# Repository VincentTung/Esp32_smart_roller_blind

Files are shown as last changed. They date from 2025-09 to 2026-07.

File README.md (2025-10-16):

# ESP32 智能卷帘控制系统

基于ESP32和A4988步进电机驱动器的智能卷帘控制系统，支持红外遥控、蓝牙APP控制。

## 📱 系统展示

### 安装效果
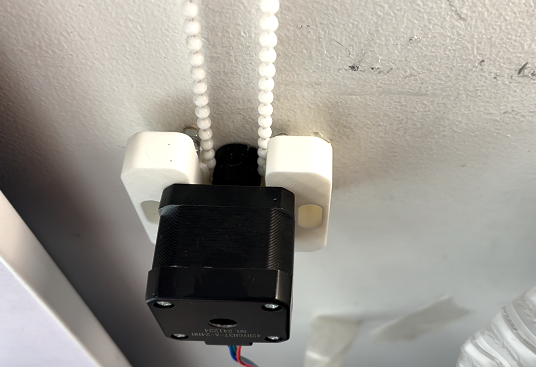
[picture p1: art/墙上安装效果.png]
墙上安装效果


### APP操作演示
APP操作演示

## 🚀 快速开始

### 硬件组件

| 组件 | 图片 | 说明 |
|---|---|---|
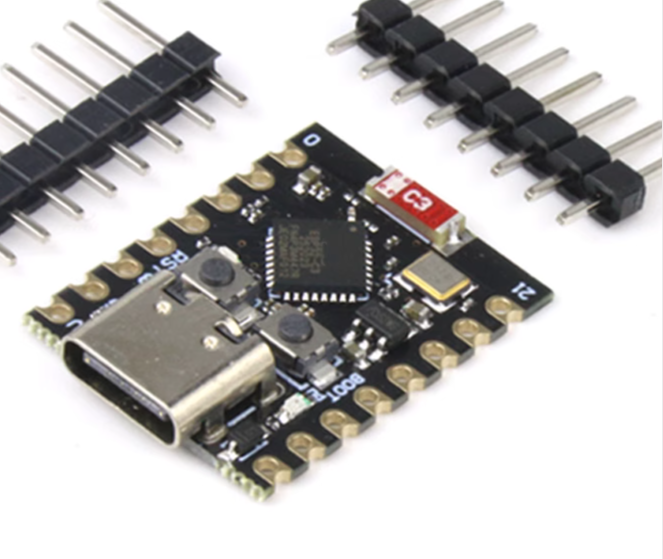
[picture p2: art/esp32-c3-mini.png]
ESP32-C3-Mini
| ESP32-C3-Mini |  | 主控制器，支持WiFi和蓝牙 |
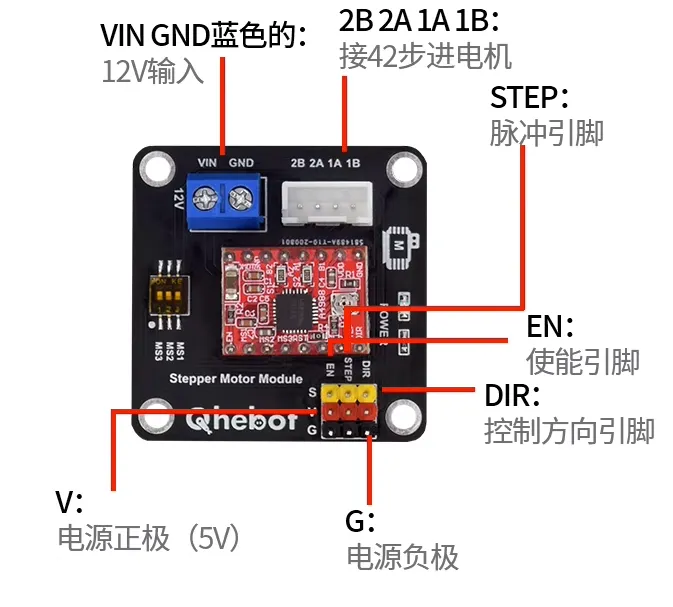
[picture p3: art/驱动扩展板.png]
驱动扩展板
| A4988驱动扩展板 |  | 步进电机驱动器 |
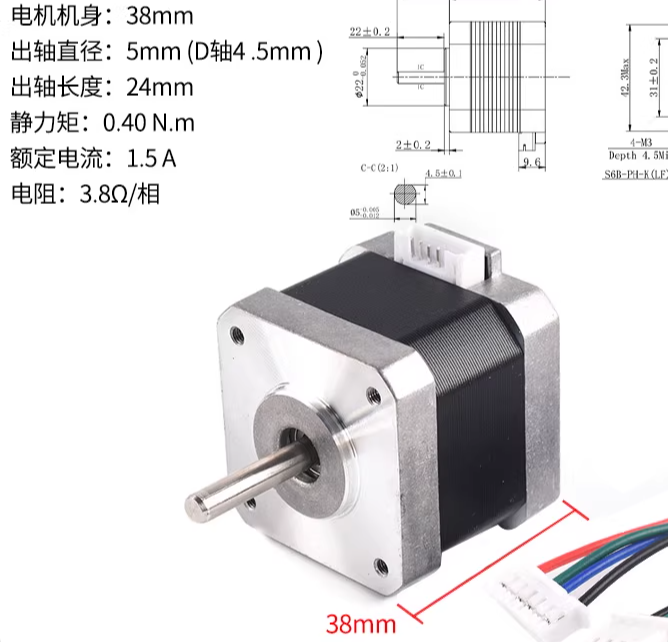
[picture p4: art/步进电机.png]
步进电机
| 42步进电机 |  | 动力源，200步/圈 |
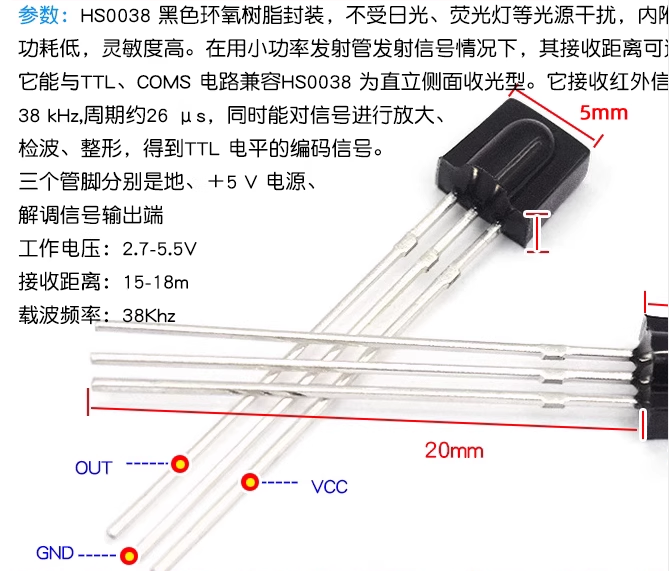
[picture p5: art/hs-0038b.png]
红外接收
| HS-0038B红外接收 |  | 红外遥控接收模块 |
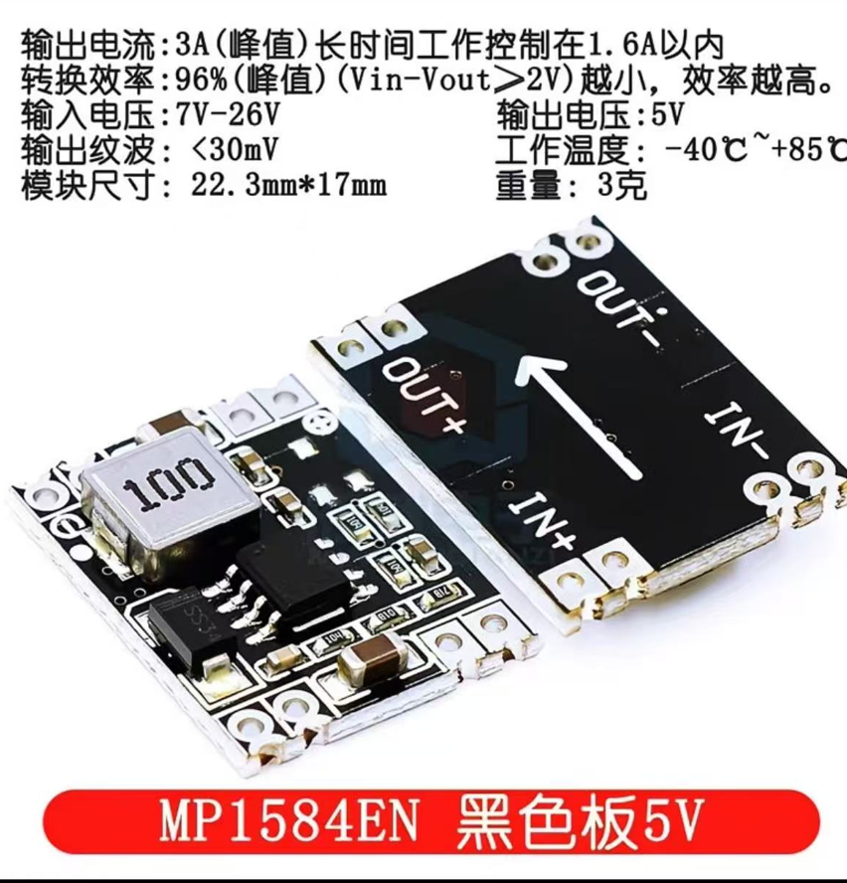
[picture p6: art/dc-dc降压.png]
DC-DC降压
| DC-DC降压模块 |  | 12V转5V电源转换 |
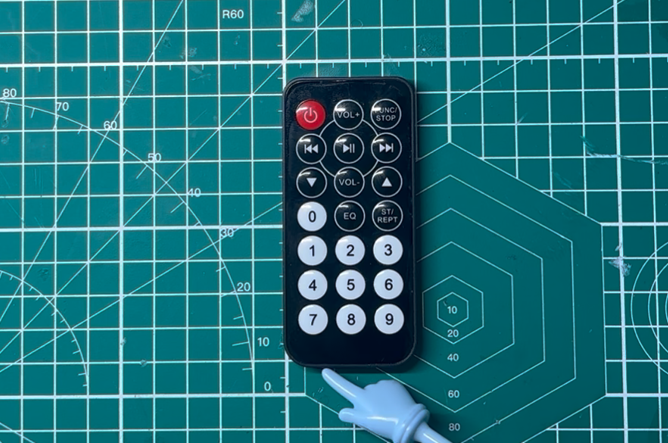
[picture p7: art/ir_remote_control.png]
红外遥控器
| 红外遥控器 |  | 遥控操作设备 |

### 硬件连接
```
ESP32 GPIO 6  -> A4988 STEP
ESP32 GPIO 7  -> A4988 DIR  
ESP32 GPIO 8  -> A4988 ENABLE
ESP32 GPIO 9  -> 红外接收模块 OUT
ESP32 3.3V    -> A4988 VDD, 红外接收模块 VCC
ESP32 GND     -> A4988 GND, 红外接收模块 GND
12V电源       -> A4988 VMOT
12V电源GND    -> A4988 GND
```

## 📱 Android APP

### 功能特性
- **蓝牙连接**: 通过BLE与ESP32设备连接
- **实时控制**: 支持窗帘的开启、关闭、停止操作
- **状态显示**: 实时显示设备连接状态和窗帘位置
- **微调功能**: 支持小幅度的窗帘位置调整
- **设置模式**: 可进入设置模式校准窗帘运行时间

### APP安装
1. 下载 `archives/app-release.apk`
2. 在Android设备上安装APK文件
3. 打开APP并授予蓝牙权限
4. 搜索并连接ESP32设备

### APP界面说明
- **连接状态**: 显示设备连接状态
- **控制按钮**: 开启、关闭、停止、微调等操作
- **设置按钮**: 进入时间设置模式
- **刷新按钮**: 重新搜索设备

## 🎮 控制方式

### 红外遥控器功能

| 按键 | 功能 | 说明 |
|---|---|---|
| 上键 | 升起窗帘 | 转动设定时间 |
| 下键 | 放下窗帘 | 转动设定时间 |
| 左键 | 微调升起 | 短时间调整 |
| 右键 | 微调放下 | 短时间调整 |
| 设置键 | 时间设置 | 进入/退出设置模式 |
| 中间键 | 停止电机 | 紧急停止 |
| 0键 | 切换方向 | 改变电机转动方向 |

### 蓝牙APP控制
- **升起/下降**: 通过APP按钮控制窗帘完全开启或关闭
- **停止**: 随时停止窗帘运动
- **微调升起/微调下降**: 小幅度的位置调整
- **设置**: 进入时间校准模式

## ⚙️ 时间设置

### 设置步骤
1. 按**设置键**（遥控器）或点击**设置按钮**（APP）进入设置模式
2. 系统开始关闭窗帘并计时
3. 窗帘完全关闭后，再次按**设置键**或点击**设置按钮**
4. 时间自动保存到EEPROM

### 调试信息
运行项目后，观察串口调试信息：
```
[14:37:16.671] [IR] 协议:8 地址:0x80 命令:0x1E
[14:37:16.705] [INFO] 接收到有效红外命令: 0x1E
[14:37:16.705] [WARN] 未知命令: 0x1E - 请使用正确的按键或检查遥控器
```

## 🔧 技术参数

- **电机**: 42步进电机，200步/圈，1/16微步进
- **速度**: 600步/秒（可调200-1000）
- **默认时间**: 5000毫秒
- **微调时间**: 1000毫秒
- **红外地址**: 0xBF00
- **蓝牙**: BLE 4.0
- **电源**: 12V直流供电

## 📁 项目结构

```
Esp32_smart_roller_blind/
├── code/
│   ├── arduino_esp32/                    # ESP32固件代码
│   │   └── skech_smart_roller_blind/
│   │       ├── skech_smart_roller_blind.ino  # 主程序
│   │       ├── BLEHandler.cpp/.h         # 蓝牙处理
│   │       └── config.h                  # 配置文件
│   └── android/                          # Android APP源码
│       └── RollerBlindControllerApp/
├── 3dmodel/                              # 3D打印文件
│   ├── gear.stl                          # 齿轮
│   └── mount.stl                         # 支架
├── art/                                  # 硬件图片和APP截图
├── archives/                             # 发布文件
│   ├── app-release.apk                   # Android APP安装包
│   └── smart_roller_blind_*.bin          # ESP32固件
└── README.md
```

## 🛠️ 开发环境

### Arduino固件开发
1. 安装Arduino IDE
2. 安装ESP32开发板支持包
3. 安装IRremote库
4. 上传代码到ESP32

### Android APP开发
1. 安装Android Studio
2. 导入项目到Android Studio
3. 配置Gradle依赖
4. 编译生成APK

## 🖨️ 3D打印

**注意**: 3D模型来自 [Printables](https://printables.com/model/1328338-high-torque-motorised-roller-blinds-mount)

感谢作者Tmate，请尊重模型的版权。

项目包含完整的3D打印文件：
- `gear.stl` - 齿轮
- `mount.stl` - 支架

## 🔍 故障排除

| 问题 | 解决方案 |
|---|---|
| 电机不转 | 检查12V电源和A4988连接 |
| 红外无响应 | 检查HS-0038B模块连接和遥控器电池 |
| 蓝牙连接失败 | 检查ESP32蓝牙功能，重启设备 |
| APP无法连接 | 确认设备在蓝牙范围内，重新搜索 |
| 转动不准确 | 重新进入设置模式校准时间 |
| 设置不保存 | 连续3次按中间键清除存储 |

## ⚠️ 安全注意事项

- 调试过程中严格操作，注意安全
- 使用12V电源，确保电源适配器质量
- 确保所有连接牢固，避免松动
- 避免短路和过载
- 安装时注意窗帘重量，确保支架牢固

## 📄 许可证

本项目仅供学习和个人使用，请遵守相关法律法规。

## 🤝 贡献

欢迎提交Issue和Pull Request来改进项目。

---

**项目特色**: 支持红外遥控和蓝牙APP双重控制，操作简单，安装方便。

---

⭐ 如果这个项目对您有帮助，请给我一个Star！

⭐ 如果您觉得我帮你节省了大量的开发时间，请扫描下方的二维码随意打赏，要是能打赏个 10.24 🐵就太👍了。您的支持将鼓励我继续进行分享。
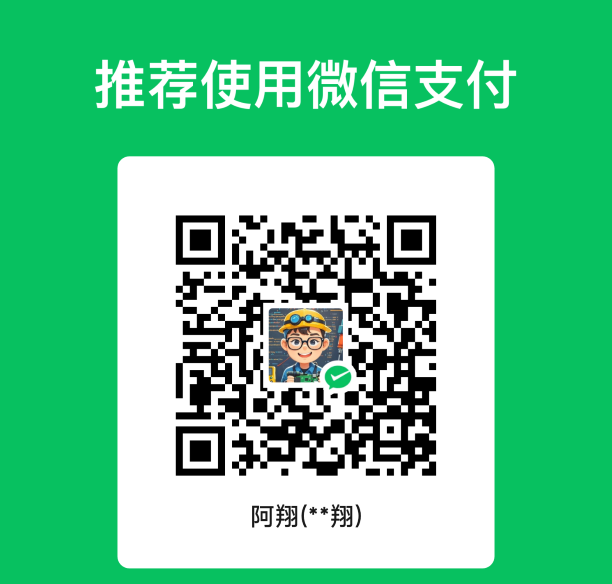
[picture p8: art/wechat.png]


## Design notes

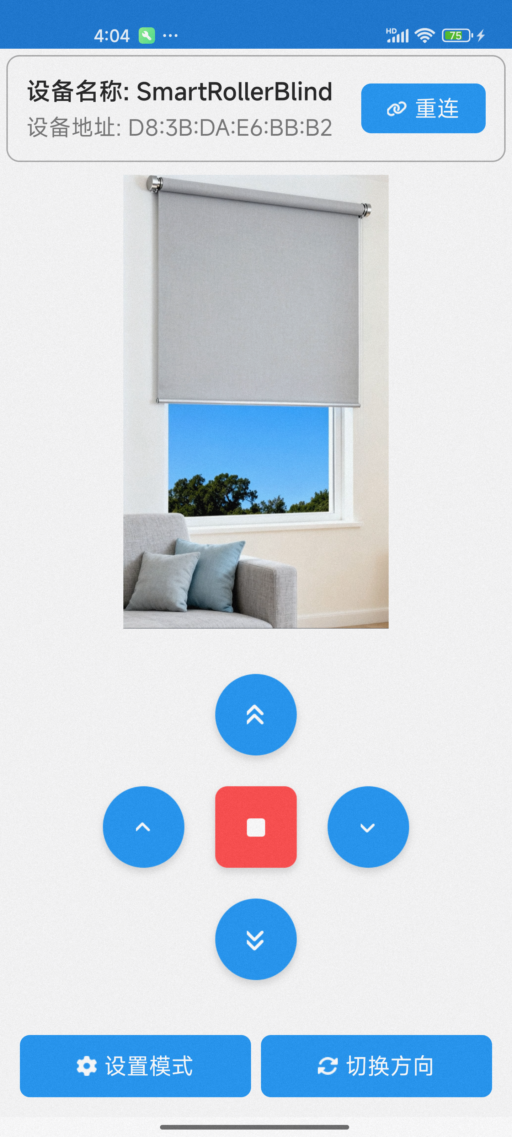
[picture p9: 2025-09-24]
art/app_screen_capture.png

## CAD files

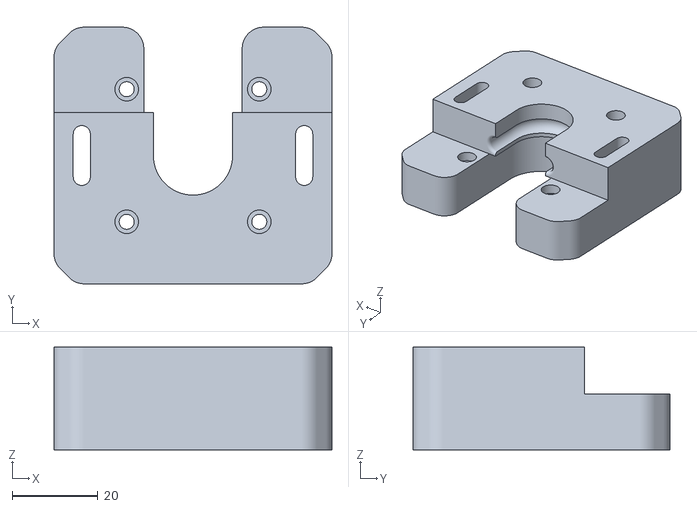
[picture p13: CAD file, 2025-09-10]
3dmodel/mount.stl
65.0 x 60.0 x 24.0

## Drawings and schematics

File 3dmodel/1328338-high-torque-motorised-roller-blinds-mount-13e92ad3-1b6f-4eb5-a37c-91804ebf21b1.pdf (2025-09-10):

## High-torque motorised roller

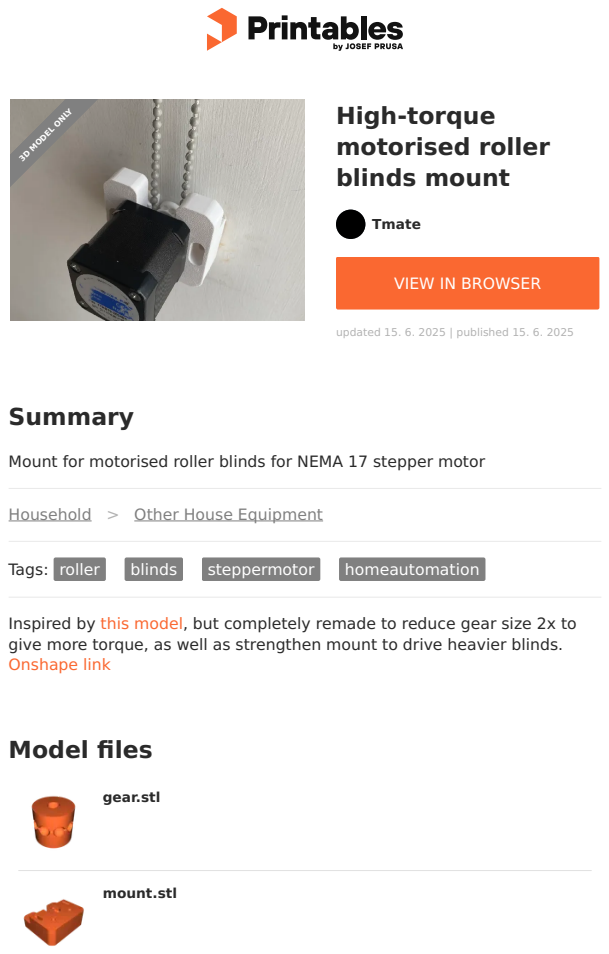
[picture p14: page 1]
Model files; Summary; Tags: roller; blinds; steppermotor; homeautomation; Tmate; blinds mount; updated 15. 6. 2025 | published 15. 6. 2025; gear.stl; mount.stl; 3D MODEL ONLY

VIEW IN BROWSER (https://printables.com/model/1328338-high-torque-motorised-roller-blinds-mount)

Mount for motorised roller blinds for NEMA 17 stepper motor

Household (https://printables.com/model?categoryId=3) > Other House Equipment (https://printables.com/model?categoryId=45)

Inspired by this model, (https://www.printables.com/model/465889-minimalistic-motorized-roller-blinds-nema-17-stepp) but completely remade to reduce gear size 2x to
give more torque, as well as strengthen mount to drive heavier blinds.
Onshape link (https://cad.onshape.com/documents/c4e8abff95d68b801ce2675b/w/7b95d8b326376692f4b0efbf/e/11ea789fce436373b3d73381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)

## License

This work is licensed under a
Creative Commons (4.0 International License)

Attribution-NonCommercial (http://creativecommons.org/licenses/by-nc/4.0/)

✖ | Sharing without ATTRIBUTION
✔ | Remix Culture allowed
✖ | Commercial Use
✖ | Free Cultural Works
✖ | Meets Open Definition

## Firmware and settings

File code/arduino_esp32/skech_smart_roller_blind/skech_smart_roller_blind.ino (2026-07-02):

/*
 * ESP32 + A4988 步进电机 + 红外接收控制程序
 * 适用于42步进电机 - 窗帘控制系统
 * 
 * 红外遥控器按键功能 (基于实际命令码):
 * 上键 (0x1) - 升起窗帘 (默认:逆时针转动指定时间)
 * 下键 (0x9) - 放下窗帘 (默认:顺时针时针转动指定时间)
 * 左键 (0x4) - 默认:升起窗帘(微调)
 * 右键 (0x6) - 默认:放下转动(微调)
 * 设置键 (0xE) - 进入设置模式开始计时关闭 / 停止计时保存时间
 * 中间键 (0x5) - 停止电机 / 连续3次清除存储
 *  9键  (0x1A) - 切换电机转动方向
 */

#include <IRremote.h>// 必须在 IRremote.h 之后，IRremote 会 #undef DEBUG_PRINT/DEBUG_PRINTLN
#include "config.h"
#include <EEPROM.h>
#include "BLEHandler.h"


// 电机参数（从config.h获取）
int speed = DEFAULT_MOTOR_SPEED;  // 步/秒 (流畅转动)

// 窗帘控制时间设置
int currentCurtainTime = DEFAULT_CURTAIN_TIME;  // 窗帘开关时间 (毫秒) - 可修改

//方向设置（可动态切换）
bool isNormalDirection = true;  // 默认方向

// 电机状态
bool motorRunning = false;
volatile bool stopRequested = false;  // 停止请求标志

// 窗帘状态标志位
bool isFullyRolledUp = false;    // 是否完全升起
bool isFullyRolledDown = false;  // 是否完全放下

// 设置模式状态
bool setMode = false;           // 是否处于设置模式
bool timingInProgress = false;  // 是否正在计时
unsigned long timingStart = 0;  // 计时开始时间
int shutdownCount = 0;          // 连续关机按键计数
unsigned long lastShutdownTime = 0; // 上次关机按键时间


// 红外接收状态
uint32_t lastIRCommand = 0;
unsigned long lastIRTime = 0;
const unsigned long IR_DEBOUNCE_TIME = 200; // 200ms防抖时间

// BLE处理器
#if ENABLE_BLE
BLEHandler* bleHandler = nullptr;
#endif


// BLE命令队列（用于非阻塞处理）
volatile bool bleStopRequested = false;
volatile bool bleUpRequested = false;
volatile bool bleDownRequested = false;
volatile bool bleLeftRequested = false;
volatile bool bleRightRequested = false;
volatile bool bleSetRequested = false;
volatile bool bleDirectionRequested = false;
 
 // 辅助函数：重置窗帘状态
void resetCurtainState() {
  isFullyRolledUp = false;
  isFullyRolledDown = false;
  stopRequested = false;
}

// 辅助函数：获取方向参数
bool getDirection(bool isUp) {
  if (isUp) {
    return isNormalDirection; // 升起方向
  } else {
    return !isNormalDirection; // 放下方向
  }
}

// 辅助函数：验证红外命令有效性
bool isValidIRCommand(uint32_t command, uint8_t protocol) {
  return command != 0xFFFFFFFF && protocol != 0;
}

// 辅助函数：判断是否应该处理命令（防抖机制）
bool shouldProcessCommand(uint32_t command, unsigned long currentTime, unsigned long debounceTime) {
  return command != lastIRCommand || (currentTime - lastIRTime) > debounceTime;
}

// 辅助函数：更新红外状态
void updateIRState(uint32_t command, unsigned long currentTime) {
  lastIRCommand = command;
  lastIRTime = currentTime;
}

// 辅助函数：打印红外信号详细信息
void printIRSignal(uint32_t address, uint32_t command, uint8_t protocol, const char* context = "") {
  DEBUG_PRINT("红外信号");
  if (strlen(context) > 0) {
    DEBUG_PRINT(" [");
    DEBUG_PRINT(context);
    DEBUG_PRINT("]");
  }
  DEBUG_PRINT(" - 协议:");
  DEBUG_PRINT(protocol);
  DEBUG_PRINT(" 地址:0x");
  DEBUG_PRINTF("%X", address);
  DEBUG_PRINT(" 命令:0x");
  DEBUG_PRINTF("%X", command);
  DEBUG_PRINT(" 位数:");
  DEBUG_PRINT(IrReceiver.decodedIRData.numberOfBits);
  DEBUG_PRINT(" 标志:");
  DEBUG_PRINTF("%X", IrReceiver.decodedIRData.flags);
  DEBUG_PRINTLN();
}

// 电源管理函数（简化版 - 已移除睡眠逻辑）

bool executeStepControl(unsigned long stepDelay, unsigned long &lastStepTime, bool &stepState, int &totalSteps, unsigned long startTime, bool isSetMode = false) {
  unsigned long currentTime = millis();
  if (currentTime - lastStepTime >= stepDelay / 1000) {  // 转换为毫秒
    // 执行步进脉冲 - 与rotateForTime完全相同的逻辑
    if (!stepState) {
      digitalWrite(STEP_PIN, HIGH);
      stepState = true;
    } else {
      digitalWrite(STEP_PIN, LOW);
      stepState = false;
      lastStepTime = currentTime; // 在LOW状态时更新时间，确保时序准确
      totalSteps++;
      
      // 每2000步打印一次进度
      if (totalSteps % 2000 == 0) {
        unsigned long elapsed = currentTime - startTime;
        if (isSetMode) {
          Serial.print("设置模式 - 已执行 ");
        } else {
          Serial.print("已执行 ");
        }
        Serial.print(totalSteps);
        Serial.print(" 步，用时 ");
        Serial.print(elapsed);
        Serial.println(" 毫秒");
      }
    }
    return true; // 执行了步进
  }
  return false; // 未执行步进
}

// 设置模式旋转处理函数 - 使用与rotateForTime完全相同的方法
void handleSetModeRotation() {
  // 确保电机已启用
  digitalWrite(ENABLE_PIN, LOW);
  
  // 使用与rotateForTime完全相同的步进控制逻辑
  static unsigned long stepDelay = 1000000 / speed;
  static unsigned long lastStepTime = 0;
  static bool stepState = false;
  static int totalSteps = 0;
  static unsigned long lastSetModeTime = 0;
  static unsigned long startTime = 0;
  static bool directionSet = false;
  static bool setModeRunning = false;
  
  // 每次进入设置模式时重新初始化所有变量
  if (timingStart != lastSetModeTime) {
    stepState = false;
    lastStepTime = 0;
    totalSteps = 0;
    lastSetModeTime = timingStart;
    startTime = millis();
    directionSet = false;
    setModeRunning = true;
    stepDelay = 1000000 / speed; // 重新计算步进延迟
  }
  
  // 设置方向（只设置一次）
  if (!directionSet) {
    digitalWrite(DIR_PIN, getDirection(false) ? HIGH : LOW); // 放下方向
    directionSet = true;
  }
  
  // 检查停止标志
  #if ENABLE_BLE
    if (bleStopRequested || stopRequested) {
      exitSetMode();
      return;
    }
  #else
    if (stopRequested) {
      exitSetMode();
      return;
    }
  #endif
  
  // 使用与rotateForTime完全相同的执行方式：在循环中连续执行步进控制
  if (setModeRunning) {
    // 使用与rotateForTime完全相同的步进控制函数
    if (executeStepControl(stepDelay, lastStepTime, stepState, totalSteps, startTime, true)) {
      // 每10步检查一次停止标志（与rotateForTime保持一致）
      if (totalSteps % 10 == 0) {
        #if ENABLE_BLE
          if (bleStopRequested || stopRequested) {
            exitSetMode();
            return;
          }
        #else
          if (stopRequested) {
            exitSetMode();
            return;
          }
        #endif
      }
    }
    
    // 与rotateForTime保持完全一致：让出CPU时间给其他任务
    delay(1);  
    
  }
}

// 退出设置模式
void exitSetMode() {
  unsigned long duration = millis() - timingStart;
  Serial.print("设置模式结束，窗帘关闭时间: ");
  Serial.print(duration);
  Serial.println(" 毫秒");
  
  // 停止电机
  digitalWrite(ENABLE_PIN, HIGH);
  motorRunning = false;
  timingInProgress = false;
  setMode = false;
  
  Serial.print("exitSetMode() 设置 setMode = ");
  Serial.println(setMode ? "true" : "false");
  
  // 保存时间
  currentCurtainTime = duration;
  saveCurtainTime();
  isFullyRolledDown = true;
  isFullyRolledUp = false;
  
  // 清除停止标志
  stopRequested = false;
  #if ENABLE_BLE
    bleStopRequested = false;
  #endif
  
  Serial.println("=== 退出设置模式 ===");
}

// 打印设置模式状态
void printSetModeStatus(unsigned long elapsed, int totalSteps, unsigned long stepDelay) {
  DEBUG_PRINT("设置模式 - 已计时: ");
  DEBUG_PRINT(elapsed);
  DEBUG_PRINT(" 毫秒 (转速: ");
  DEBUG_PRINT(speed);
  DEBUG_PRINT(" 步/秒, 总步数: ");
  DEBUG_PRINT(totalSteps);
  DEBUG_PRINT(", 步进延迟: ");
  DEBUG_PRINT(stepDelay);
  DEBUG_PRINT(" 微秒, 实际转速: ");
  if (elapsed > 0) {
    DEBUG_PRINT((totalSteps * 1000) / elapsed);
    DEBUG_PRINT(" 步/秒");
  } else {
    DEBUG_PRINT("计算中");
  }
  DEBUG_PRINTLN(")");
}

void setup() {
   Serial.begin(9600);
   DEBUG_PRINTLN("ESP32-C3 + A4988 步进电机 + 红外控制");
   
   // 设置引脚
   pinMode(STEP_PIN, OUTPUT);
   pinMode(DIR_PIN, OUTPUT);
   pinMode(ENABLE_PIN, OUTPUT);
   
   // 初始状态
   digitalWrite(STEP_PIN, LOW);
   digitalWrite(DIR_PIN, LOW);
   digitalWrite(ENABLE_PIN, HIGH);  // 禁用电机（待机状态）
  // 读取存储的窗帘时间
  loadCurtainTime();
  
  // 读取存储的方向设置
  loadDirectionSetting();
  // 初始化红外接收 (0038k模块)
  DEBUG_PRINT("初始化红外接收模块，引脚: ");
  DEBUG_PRINTLN(IR_RECEIVE_PIN);
  IrReceiver.begin(IR_RECEIVE_PIN, false);
  DEBUG_PRINTLN("红外接收模块初始化完成");
  
  // 初始化BLE（根据配置决定）
  #if ENABLE_BLE
    bleHandler = new BLEHandler();
    bleHandler->init();
    bleHandler->setCommandCallbacks(
      handleBLEUpCommand,      // 升起窗帘
      handleBLEDownCommand,    // 放下窗帘
      handleBLELeftCommand,    // 微调升起
      handleBLERightCommand,   // 微调放下
      handleBLEStopCommand,    // 停止电机
      handleBLESetCommand,     // 设置模式
      handleBLEDirectionCommand // 切换方向
    );
    bleHandler->startAdvertising();
    Serial.println("BLE已初始化并开始广播");
  #else
    Serial.println("BLE已禁用（节省电量）");
  #endif
  
  // 初始化窗帘状态标志位
  isFullyRolledUp = false;
  isFullyRolledDown = false;
  
  // 初始化完成
  
  DEBUG_PRINTLN("电机已启用，0038k红外接收模块已初始化");
  #if ENABLE_BLE
    Serial.println("等待红外命令或BLE命令...");
  #else
    Serial.println("等待红外命令...");
  #endif
  printIRCommands();
   

 }
 
void loop() {
  // 在设置模式下减少BLE状态检查频率，避免影响电机转动
  #if ENABLE_BLE
    static unsigned long lastBLEStatusTime = 0;
    if (!setMode && millis() - lastBLEStatusTime > 10000) { // 非设置模式下每10秒检查一次
      DEBUG_PRINTLN(bleHandler != nullptr ? "BLE处理器状态正常" : "BLE处理器为空！");
      lastBLEStatusTime = millis();
    }
  #endif
  
  // 处理BLE命令队列（优先级最高）
  #if ENABLE_BLE
    if (bleStopRequested) {
      bleStopRequested = false;
      stopRequested = true;
      stopMotor();
    }
    
    if (bleUpRequested) {
      bleUpRequested = false;
      if (!isFullyRolledUp) {
        resetCurtainState();
        rollUpCurtain();
      }
    }
    
    if (bleDownRequested) {
      bleDownRequested = false;
      if (!isFullyRolledDown) {
        resetCurtainState();
        layDownCurtain();
      }
    }
    
    if (bleLeftRequested) {
      bleLeftRequested = false;
      resetCurtainState();
      rotateForTime(SIDE_KEY_TIME, getDirection(true)); // 微调升起
    }
    
    if (bleRightRequested) {
      bleRightRequested = false;
      resetCurtainState();
      rotateForTime(SIDE_KEY_TIME, getDirection(false)); // 微调放下
    }
    
    if (bleSetRequested) {
      bleSetRequested = false;
      handleSetKey();
    }
    
    if (bleDirectionRequested) {
      bleDirectionRequested = false;
      handleDirectionKey();
    }
  #endif
  
  // 检查红外信号
  if (IrReceiver.decode()) {
    DEBUG_PRINTLN("检测到红外信号！");
    uint32_t address = IrReceiver.decodedIRData.address;
    uint32_t command = IrReceiver.decodedIRData.command;
    uint8_t protocol = IrReceiver.decodedIRData.protocol;
    
    // 打印所有接收到的红外信号（包括无效信号）
    printIRSignal(address, command, protocol, "接收");
    
    // 过滤无效信号：协议:0、地址:0x0、命令:0x0 不处理
    if (protocol == 0 && address == 0x0 && command == 0x0) {
      DEBUG_PRINTLN("无效信号，忽略");
      IrReceiver.resume();
      return; 
    }
    
  // 在设置模式下，最小化红外信号处理，优先保证步进控制
  if (setMode) {
    // 设置模式下只处理有效地址的信号，快速跳过无效信号
    if (address != IR_ADDRESS) {
      IrReceiver.resume();
      return;
    }
    
    // 设置模式下快速处理命令，减少阻塞时间
    unsigned long currentTime = millis();
    if (isValidIRCommand(command, protocol)) {
      if (shouldProcessCommand(command, currentTime, 200)) { // 设置模式防抖时间：200ms
        DEBUG_PRINT("设置模式接收到有效命令: 0x");
        DEBUG_PRINTF("%X\n", command);
        handleIRCommand(command);
        updateIRState(command, currentTime);
      } else {
        DEBUG_PRINTLN("设置模式：重复命令，忽略");
      }
    } else {
      DEBUG_PRINTLN("设置模式：无效命令，忽略");
    }
    IrReceiver.resume();
    return;
  } else {
      // 非设置模式下的正常处理
      // 验证地址
      if (address != IR_ADDRESS) {
        DEBUG_PRINT("地址不匹配，期望:0x");
        DEBUG_PRINTF("%X", IR_ADDRESS);
        DEBUG_PRINT(" 实际:0x");
        DEBUG_PRINTF("%X\n", address);
        IrReceiver.resume();
        return;
      }
      
      DEBUG_PRINTLN("地址匹配，处理命令");
    }

    unsigned long currentTime = millis();
    
    // 非设置模式下的正常处理
    if (isValidIRCommand(command, protocol)) {
      // 电机运行时立即处理停止命令，否则使用防抖机制
      if (motorRunning && command == IR_KEY_SHUTDOWN) {
        DEBUG_PRINTLN("电机运行时接收到有效停止命令，立即处理");
        handleIRCommand(command);
        updateIRState(command, currentTime);
      } else if (shouldProcessCommand(command, currentTime, IR_DEBOUNCE_TIME)) {
        DEBUG_PRINTLN("处理有效命令");
        handleIRCommand(command);
        updateIRState(command, currentTime);
      } else {
        DEBUG_PRINTLN("重复命令，已忽略");
      }
    } else {
      DEBUG_PRINTLN("无效信号，已忽略");
    }
    
    IrReceiver.resume();
  }
  
  // 检查设置模式下的持续转动
  if (setMode && timingInProgress && motorRunning) {
    handleSetModeRotation();
  }
  
  // 调试输出：在非设置模式下每30秒显示一次状态，设置模式下不输出
  static unsigned long lastDebugTime = 0;
  if (!setMode && millis() - lastDebugTime > 30000) {
    DEBUG_PRINT("系统运行中 - setMode: ");
    DEBUG_PRINT(setMode ? "true" : "false");
    DEBUG_PRINT(", timingInProgress: ");
    DEBUG_PRINT(timingInProgress ? "true" : "false");
    DEBUG_PRINT(", motorRunning: ");
    DEBUG_PRINT(motorRunning ? "true" : "false");
    DEBUG_PRINT(", 等待红外信号...");
    DEBUG_PRINTLN();
    lastDebugTime = millis();
  }
  
  // 正常运行
 
  if (!setMode) {
    delay(IDLE_DELAY_MS); // 使用配置的延迟时间，避免过度占用CPU
  }
  // 设置模式下不添加任何延迟，因为handleSetModeRotation内部已有delay(1)
  
  // 安全措施：如果不在设置模式且电机应该停止，确保电机被禁用
  if (!setMode && !motorRunning) {
    digitalWrite(ENABLE_PIN, HIGH);  // 确保电机被禁用
  }
}

// 转动指定时长 (毫秒) - 非阻塞版本
void rotateForTime(int duration, bool clockwise) {
  Serial.print("rotateForTime函数接收参数: duration=");
  Serial.print(duration);
  Serial.print(", clockwise=");
  Serial.println(clockwise ? "true" : "false");
  
  digitalWrite(ENABLE_PIN, LOW);  // 启用电机
  digitalWrite(DIR_PIN, clockwise ? HIGH : LOW);
  
  unsigned long startTime = millis();
  unsigned long stepDelay = 1000000 / speed;
  int stepCount = 0;
  unsigned long lastStepTime = 0;
  
  Serial.print("开始旋转，持续时间: ");
  Serial.print(duration);
  Serial.print(" 毫秒，方向: ");
  Serial.println(clockwise ? "顺时针" : "逆时针");
  Serial.print("步进延迟: ");
  Serial.print(stepDelay);
  Serial.println(" 微秒");
  
  // 完全非阻塞方式：使用状态机而不是while循环
  bool stepState = false;  // 移除static，每次调用函数时重新初始化
  while (millis() - startTime < duration) {
    // 每次循环都检查停止标志（提高响应速度）
    #if ENABLE_BLE
      if (bleStopRequested) {
        Serial.println("旋转过程中接收到BLE停止命令，立即停止");
        bleStopRequested = false;  // 清除标志
        break;
      }
    #endif
    
    if (stopRequested) {
      Serial.println("旋转过程中接收到停止命令，立即停止");
      break;
    }
    
    // 使用统一的步进控制函数，确保与设置模式完全一致
    if (executeStepControl(stepDelay, lastStepTime, stepState, stepCount, startTime, false)) {
      // 每10步检查一次红外信号（减少检查频率提高流畅性）
      if (stepCount % 10 == 0) {
        // 检查红外信号
        if (IrReceiver.decode()) {
          uint32_t command = IrReceiver.decodedIRData.command;
          uint32_t address = IrReceiver.decodedIRData.address;
          uint8_t protocol = IrReceiver.decodedIRData.protocol;
          
          // 只有在接收到有效的停止信号时才停止（地址不为0x0，协议不为0）
          if (command == IR_KEY_SHUTDOWN && address != 0x0 && protocol != 0) {
            DEBUG_PRINTLN("旋转过程中接收到有效红外停止信号，立即停止");
            stopRequested = true;
            IrReceiver.resume();
            break;
          }
          IrReceiver.resume();
        }
      }
    }
    
    delay(1);  // 1毫秒延迟，让BLE回调有机会执行
  }
  
  unsigned long actualDuration = millis() - startTime;
  Serial.print("旋转完成，总步数: ");
  Serial.print(stepCount);
  Serial.print("，实际持续时间: ");
  Serial.print(actualDuration);
  Serial.print(" 毫秒，停止原因: ");
  Serial.println(stopRequested ? "被中断" : "时间到");
  
  // 确保电机被禁用
  digitalWrite(ENABLE_PIN, HIGH);
}

// 设置速度
void setSpeed(int newSpeed) {
  speed = constrain(newSpeed, MIN_MOTOR_SPEED, MAX_MOTOR_SPEED);  // 限制速度范围，流畅转动设置
  DEBUG_PRINT("速度设置为: ");
  DEBUG_PRINT(speed);
  DEBUG_PRINTLN(" 步/秒");
}
 
// 打印红外命令说明
void printIRCommands() {
  Serial.println("红外遥控器按键功能:");
  Serial.print("上键 (0x1) - 窗帘升起");
  Serial.print(currentCurtainTime);
  Serial.println("毫秒)");
  Serial.print("下键 (0x9) - 窗帘放下");
  Serial.print(currentCurtainTime);
  Serial.println("毫秒)");
  Serial.println("左键 (0x4) - 微调升起");
  Serial.println("右键 (0x6) - 微调放下");
  Serial.println("设置键 (0xE) - 进入设置模式开始计时关闭 / 停止计时保存时间");
  Serial.println("0键 (0x0) - 停止电机 / 连续3次清除存储");
  Serial.println("方向键 (0x1A) - 切换电机转动方向");
  Serial.println("-------------------");
}
 
// 处理红外命令
void handleIRCommand(uint32_t command) {
  DEBUG_PRINT("接收到有效红外命令: 0x");
  DEBUG_PRINTF("%X\n", command);
  
  switch (command) {
    case IR_KEY_UP:
      if (isFullyRolledUp) {
        DEBUG_PRINTLN("窗帘已经完全升起，停止动作");
        break;
      }
      DEBUG_PRINTLN("执行: 窗帘升起");
      DEBUG_PRINT("isNormalDirection = ");
      DEBUG_PRINTLN(isNormalDirection ? "true" : "false");
      isFullyRolledDown = false;
      isFullyRolledUp = false;
      rollUpCurtain();
      break;
      
    case IR_KEY_DOWN:
      if (isFullyRolledDown) {
        Serial.println("窗帘已经完全放下，无响应");
        break;
      }
      isFullyRolledDown = false;
      isFullyRolledUp = false;
      Serial.println("执行: 窗帘放下");
      Serial.print("isNormalDirection = ");
      Serial.println(isNormalDirection ? "true" : "false");
      layDownCurtain();
      break;
      
    case IR_KEY_LEFT: {
      Serial.println("执行: 微调升起（丝滑模式）");
      resetCurtainState();
      rotateForTime(SIDE_KEY_TIME, getDirection(true)); // 微调升起
      break;
    }
      
    case IR_KEY_RIGHT: {
      Serial.println("执行: 微调放下（丝滑模式）");
      resetCurtainState();
      rotateForTime(SIDE_KEY_TIME, getDirection(false)); // 微调放下
      break;
    }
      
    case IR_KEY_SET:
      handleSetKey();
      break;
      
    case IR_KEY_SHUTDOWN:
      handleShutdownKey();
      break;
      
    case IR_KEY_DIRECTION:
      handleDirectionKey();
      break;
      
    default:
      Serial.print("未知命令: 0x");
      Serial.print(command, HEX);
      break;
  }
}
 
// 停止电机
void stopMotor() {
  digitalWrite(ENABLE_PIN, HIGH);  // 禁用电机
  motorRunning = false;
  
  // 如果在设置模式下停止，需要退出设置模式
  if (setMode) {
    exitSetMode();
  }
  
  Serial.println("电机已停止");
  delay(100);
  // 注意：不重新启用电机，保持待机状态
}

// 打开窗帘
void rollUpCurtain() {
  Serial.println("=== 开始升起窗帘 ===");
  DEBUG_PRINT("当前速度设置: ");
  DEBUG_PRINT(speed);
  DEBUG_PRINTLN(" 步/秒");
  
  motorRunning = true;
  stopRequested = false;  // 重置停止标志
  
  rotateForTime(currentCurtainTime, getDirection(true));
  
  motorRunning = false;
  if (!stopRequested) {
    Serial.println("窗帘已升起");
    isFullyRolledUp = true;
    isFullyRolledDown = false;
  } else {
    Serial.println("窗帘升起被中断");
  }
  
  stopRequested = false;
  Serial.println("=== 升起窗帘完成 ===");
}

// 放下窗帘
void layDownCurtain() {
  motorRunning = true;
  stopRequested = false;
  rotateForTime(currentCurtainTime, getDirection(false));
  
  motorRunning = false;
  if (!stopRequested) {
    Serial.println("窗帘已放下");
    isFullyRolledDown = true;
    isFullyRolledUp = false;
  } else {
    Serial.println("窗帘放下被中断");
  }
  
  stopRequested = false;
  Serial.println("=== 放下窗帘完成 ===");
}
 

// 处理设置键
void handleSetKey() {
  Serial.print("handleSetKey() 被调用，当前 setMode = ");
  Serial.println(setMode ? "true" : "false");
  
  if (!setMode) {
    // 进入设置模式并开始计时关闭
    Serial.println("=== 进入设置模式 ===");
    DEBUG_PRINT("当前转速: ");
    DEBUG_PRINT(speed);
    DEBUG_PRINTLN(" 步/秒 (流畅转动设置，与正常使用转速一致)");
    Serial.println("开始计时关闭窗帘，观察窗帘完全关闭后按设置键停止");
    
    setMode = true;
    timingInProgress = true;
    timingStart = millis();
    
    // 清除停止标志
    stopRequested = false;
    #if ENABLE_BLE
      bleStopRequested = false;
    #endif
    
     // 开始关闭窗帘（放下方向）
     digitalWrite(ENABLE_PIN, LOW);  // 启用电机
     digitalWrite(DIR_PIN, getDirection(false) ? HIGH : LOW);  // 放下方向
     motorRunning = true;
    
    Serial.println("设置模式：电机已启动，开始持续转动");
    DEBUG_PRINT("方向: 放下方向, 转速: ");
    DEBUG_PRINT(speed);
    DEBUG_PRINTLN(" 步/秒");
    
  } else {
    // 在设置模式中，设置停止标志（使用和BLE停止相同的方式）
    Serial.println("第二次按下SET键，设置停止标志");
    stopRequested = true;
    #if ENABLE_BLE
      bleStopRequested = true;  // 同时设置BLE停止标志，确保rotateForTime能检测到
    #endif
  }
}

// 处理关机键
void handleShutdownKey() {
  unsigned long currentTime = millis();
  
  // 检查是否在设置模式
  if (setMode) {
    Serial.println("设置模式下按关机键，退出设置模式");
    exitSetMode();
    return;
  }
  
  // 检查连续按键
  if (currentTime - lastShutdownTime < 2000) { // 2秒内
    shutdownCount++;
  } else {
    shutdownCount = 1; // 重新开始计数
  }
  
  lastShutdownTime = currentTime;
  
  if (shutdownCount >= 3) {
    // 连续3次，清除存储
    Serial.println("连续3次关机键，清除存储的时间设置");
    clearCurtainTime();
    shutdownCount = 0;
  } else {
    // 正常停止电机
    Serial.println("执行: 停止电机");
    stopRequested = true;
    stopMotor();
  }
}

// 保存窗帘时间到EEPROM
void saveCurtainTime() {
  EEPROM.begin(EEPROM_SIZE);
  EEPROM.put(EEPROM_CURTAIN_TIME_ADDR, currentCurtainTime);
  EEPROM.commit();
  EEPROM.end();
  Serial.println("窗帘时间已保存到EEPROM");
}

// 从EEPROM读取窗帘时间
void loadCurtainTime() {
  EEPROM.begin(EEPROM_SIZE);
  int savedTime;
  EEPROM.get(EEPROM_CURTAIN_TIME_ADDR, savedTime);
  EEPROM.end();
  
  if (savedTime > 0 && savedTime < 60000) { // 合理范围检查
    currentCurtainTime = savedTime;
    Serial.print("从EEPROM读取窗帘时间: ");
    Serial.print(currentCurtainTime);
    Serial.println(" 毫秒");
  } else {
    currentCurtainTime = DEFAULT_CURTAIN_TIME;
    Serial.print("使用默认窗帘时间: ");
    Serial.print(currentCurtainTime);
    Serial.println(" 毫秒");
  }
}

// 清除存储的窗帘时间
void clearCurtainTime() {
  EEPROM.begin(EEPROM_SIZE);
  EEPROM.put(EEPROM_CURTAIN_TIME_ADDR, 0); // 写入0表示无效
  EEPROM.commit();
  EEPROM.end();
  
  currentCurtainTime = DEFAULT_CURTAIN_TIME;
  Serial.print("已清除存储，恢复默认时间: ");
  Serial.print(currentCurtainTime);
  Serial.println(" 毫秒");
}

// 处理方向切换键
void handleDirectionKey() {
  // 切换方向
  Serial.print("切换前 isNormalDirection = ");
  Serial.println(isNormalDirection ? "true" : "false");
  
  if (isNormalDirection == true) {
    isNormalDirection = false;
    Serial.println("设置 isNormalDirection = false");
  } else {
    isNormalDirection = true;
    Serial.println("设置 isNormalDirection = true");
  }
  
  Serial.print("切换后 isNormalDirection = ");
  Serial.println(isNormalDirection ? "true" : "false");
  
  // 保存方向设置
  saveDirectionSetting();
  isFullyRolledUp = false;    
  isFullyRolledDown = false;
  Serial.print("方向已切换为: ");
  Serial.println(isNormalDirection ? "RIGHT模式" : "LEFT模式");
  Serial.println("新的方向设置已保存到EEPROM");
}

// 保存方向设置到EEPROM
void saveDirectionSetting() {
  EEPROM.begin(EEPROM_SIZE);
  EEPROM.put(EEPROM_DIRECTION_ADDR, isNormalDirection);  // 存储方向设置
  EEPROM.commit();
  EEPROM.end();
  Serial.println("方向设置已保存到EEPROM");
}
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

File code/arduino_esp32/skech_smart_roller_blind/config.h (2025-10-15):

#ifndef CONFIG_H
#define CONFIG_H

 // 引脚定义
 // 42步进电机
/* 
 * 连接:
 * ESP32 GPIO 6 -> A4988 STEP
 * ESP32 GPIO 7 -> A4988 DIR
 * ESP32 GPIO 8 -> A4988 ENABLE (可选)
 * ESP32 GPIO 9 -> 红外接收模块 OUT
 * ESP32 3.3V    -> A4988 VDD, 红外接收模块 VCC
 * ESP32 GND     -> A4988 GND, 红外接收模块 GND
 * 12V电源       -> A4988 VMOT
 * 12V电源GND    -> A4988 GND
 *
 */
 #define STEP_PIN 6
 #define DIR_PIN 7
 #define ENABLE_PIN 8
 //红外
 #define IR_RECEIVE_PIN 9
 
//红外地址  （根据实际接收到的地址修改）
#define IR_ADDRESS  0xBF00
// 红外命令定义 (基于实际接收到的命令码)
#define IR_KEY_UP 0x1  // val+
#define IR_KEY_DOWN 0x9 // val-
#define IR_KEY_LEFT 0x4 // <
#define IR_KEY_RIGHT 0x6 // >
#define IR_KEY_SHUTDOWN 0x5  //关闭
#define IR_KEY_SET 0xE //   ST/REPT
#define IR_KEY_DIRECTION 0x1A  // 数字9

//开关窗帘时间默认时间
const int DEFAULT_CURTAIN_TIME = 5000;  // 默认窗帘开关时间 (毫秒)
// 左右按键转动时间设置 
const int SIDE_KEY_TIME = 1000;  // 左右按键转动时间 (毫秒) 上下微调响应参数调这个

const int DEFAULT_IS_NORMAL_DIRECTION = true;

// EEPROM 配置
#define EEPROM_SIZE 512                    // EEPROM 大小
#define EEPROM_CURTAIN_TIME_ADDR 0         // 窗帘时间存储地址
#define EEPROM_DIRECTION_ADDR 4            // 方向设置存储地址
#define EEPROM_DIRECTION_INIT_FLAG_ADDR 5  // 方向设置初始化标志地址

// BLE配置
#define ENABLE_BLE true  // 蓝牙开关：true=开启，false=关闭（节省电量）
#define BLE_DEVICE_NAME "SmartRollerBlind"
#define BLE_SERVICE_UUID "12345678-1234-1234-1234-123456789abc"
#define BLE_CHARACTERISTIC_CONTROL_UUID "12345678-1234-1234-1234-123456789def"

//微步分辨率配置
// MS1/2/3
// 默认步距角电机：200步/圈（1.8°）
// L/L/L: 全步进 (1/1) → 200步/圈
// H/L/L: 1/2 微步 → 400步/圈
// L/H/L: 1/4 微步 → 800步/圈
// H/H/L: 1/8 微步 → 1600步/圈
// H/H/H: 1/16 微步 → 3200步/圈

// 步进电机配置         // 全步进
#define DEFAULT_MOTOR_SPEED 1000   // 默认电机转速（步/秒）
#define MIN_MOTOR_SPEED 200       // 最小电机转速（步/秒）
#define MAX_MOTOR_SPEED 1000      // 最大电机转速（步/秒）

// 电源管理配置
#define ENABLE_DEBUG_OUTPUT true  // 调试输出开关：true=开启，false=关闭（节省电量）
#define IDLE_DELAY_MS 50          // 空闲时延迟（毫秒），降低CPU使用率

// 调试输出宏定义
#if ENABLE_DEBUG_OUTPUT
  #define DEBUG_PRINT(x) Serial.print(x)
  #define DEBUG_PRINTLN(x) Serial.println(x)
  #define DEBUG_PRINTF(x, ...) Serial.printf(x, __VA_ARGS__)
#else
  #define DEBUG_PRINT(x)
  #define DEBUG_PRINTLN(x)
  #define DEBUG_PRINTF(x, ...)
#endif


#endif // 

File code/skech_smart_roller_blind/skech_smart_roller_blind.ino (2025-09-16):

/*
 * ESP32 + A4988 步进电机 + 红外接收控制程序
 * 适用于42步进电机 - 窗帘控制系统
 * 
 * 红外遥控器按键功能 (基于实际命令码):
 * 上键 (0x1) - 升起窗帘 (默认:逆时针转动指定时间)
 * 下键 (0x9) - 放下窗帘 (默认:顺时针时针转动指定时间)
 * 左键 (0x4) - 默认:升起窗帘(微调)
 * 右键 (0x6) - 默认:放下转动(微调)
 * 设置键 (0xE) - 进入设置模式开始计时关闭 / 停止计时保存时间
 * 中间键 (0x5) - 停止电机 / 连续3次清除存储
 *  9键  (0x1A) - 切换电机转动方向
 */
#include "config.h"
#include <IRremote.h>
#include <EEPROM.h>


 // 电机参数
 const int STEPS_PER_REVOLUTION = 200;  // 42步进电机全步进
 const int MICROSTEPS = 16;  // 1/16微步进
 const int TOTAL_STEPS = STEPS_PER_REVOLUTION * MICROSTEPS;  // 3200步/圈
 
// 速度设置
int speed = 600;  // 步/秒 (流畅转动)

// 窗帘控制时间设置
int currentCurtainTime = DEFAULT_CURTAIN_TIME;  // 窗帘开关时间 (毫秒) - 可修改

//方向设置（可动态切换）
bool isNormalDirection = true;  // 默认方向

// 电机状态
bool motorRunning = false;
bool stopRequested = false;  // 停止请求标志

// 窗帘状态标志位
bool isFullyRolledUp = false;    // 是否完全升起
bool isFullyRolledDown = false;  // 是否完全放下

// 设置模式状态
bool setMode = false;           // 是否处于设置模式
bool timingInProgress = false;  // 是否正在计时
unsigned long timingStart = 0;  // 计时开始时间
int shutdownCount = 0;          // 连续关机按键计数
unsigned long lastShutdownTime = 0; // 上次关机按键时间


// 红外接收状态
uint32_t lastIRCommand = 0;
unsigned long lastIRTime = 0;
const unsigned long IR_DEBOUNCE_TIME = 200; // 200ms防抖时间
 
 void setup() {
   Serial.begin(9600);
   Serial.println("ESP32 + A4988 步进电机 + 红外控制");
   
   // 设置引脚
   pinMode(STEP_PIN, OUTPUT);
   pinMode(DIR_PIN, OUTPUT);
   pinMode(ENABLE_PIN, OUTPUT);
   
   // 初始状态
   digitalWrite(STEP_PIN, LOW);
   digitalWrite(DIR_PIN, LOW);
   digitalWrite(ENABLE_PIN, HIGH);  // 禁用电机（待机状态）
  // 读取存储的窗帘时间
  loadCurtainTime();
  
  // 读取存储的方向设置
  loadDirectionSetting();
  // 初始化红外接收 (0038k模块)
  IrReceiver.begin(IR_RECEIVE_PIN, false);
  
  // 初始化窗帘状态标志位
  isFullyRolledUp = false;
  isFullyRolledDown = false;
  
  Serial.println("电机已启用，0038k红外接收模块已初始化");
  Serial.println("等待红外命令...");
  printIRCommands();
   

 }
 
void loop() {
  // 检查红外信号（设置模式下减少处理频率）
  if (IrReceiver.decode()) {

    uint32_t address = IrReceiver.decodedIRData.address;
    uint32_t command = IrReceiver.decodedIRData.command;
    uint8_t protocol = IrReceiver.decodedIRData.protocol;
    // 显示接收到的原始数据（用于调试）
    Serial.print("0038k接收 - 协议:");
    Serial.print(protocol);
    Serial.print(" 地址:0x");
    Serial.print(address, HEX);
    Serial.print(" 命令:0x");
    Serial.println(command, HEX);
    if(address != IR_ADDRESS){
       IrReceiver.resume();
        Serial.println("address not equals,return");
       return;
    }

    unsigned long currentTime = millis();
    
    // 在设置模式下，只处理关键命令，减少干扰
    if (setMode) {
      // 设置模式下只处理SET键和SHUT_DOWN键
      if ((command == IR_KEY_SET || command == IR_KEY_SHUTDOWN) && 
          command != 0xFFFFFFFF &&
          address != 0x0 && protocol != 0) {
        
        // 应用防重复机制（设置模式下使用更长的防抖时间）
        const unsigned long SET_MODE_DEBOUNCE_TIME = 1000; // 设置模式防抖时间：1秒
        if (command != lastIRCommand || (currentTime - lastIRTime) > SET_MODE_DEBOUNCE_TIME) {
          Serial.print("设置模式接收到命令: 0x");
          Serial.println(command, HEX);
          handleIRCommand(command);
          lastIRCommand = command;
          lastIRTime = currentTime;
        } else {
          Serial.println("设置模式：重复命令，已忽略");
        }
      }
      // 忽略其他所有信号，减少干扰
      IrReceiver.resume();
      return;
    }
    

    // 非设置模式下的正常处理
    // 验证信号有效性
    if (command != 0xFFFFFFFF) {
      // 如果电机正在运行，立即处理停止命令，跳过防重复检查
      if (motorRunning && command == IR_KEY_SHUTDOWN && address != 0x0 && protocol != 0) {
        Serial.println("电机运行时接收到有效停止命令，立即处理");
        handleIRCommand(command);
        lastIRCommand = command;
        lastIRTime = currentTime;
      }
      // 防重复命令（仅在电机不运行时）
      else if (command != lastIRCommand || (currentTime - lastIRTime) > IR_DEBOUNCE_TIME) {
        handleIRCommand(command);
        lastIRCommand = command;
        lastIRTime = currentTime;
      } else {
        Serial.println("重复命令，已忽略");
      }
    } else {
      Serial.println("无效信号，已忽略");
    }
    
    IrReceiver.resume(); // 准备接收下一个信号
  }
  
  // 检查设置模式下的持续转动
  if (setMode && timingInProgress && motorRunning) {
    // 确保电机已启用
    digitalWrite(ENABLE_PIN, LOW);  // 启用电机
    
    // 设置模式下使用与正常使用相同的转速，确保时间设置准确
    unsigned long stepDelay = 1000000 / speed;
    
    digitalWrite(STEP_PIN, HIGH);
    delayMicroseconds(1);  // 极短脉冲宽度，流畅
    digitalWrite(STEP_PIN, LOW);
    delayMicroseconds(stepDelay - 1);
    
    // 添加步数计数，用于调试
    static int totalSteps = 0;
    totalSteps++;
    
    // 每5秒显示一次计时状态
    static unsigned long lastStatusTime = 0;
    if (millis() - lastStatusTime > 5000) {
      unsigned long elapsed = millis() - timingStart;
      Serial.print("设置模式 - 已计时: ");
      Serial.print(elapsed);
      Serial.print(" 毫秒 (转速: ");
      Serial.print(speed);
      Serial.print(" 步/秒, 总步数: ");
      Serial.print(totalSteps);
      Serial.println(" - 流畅转动模式)");
      lastStatusTime = millis();
    }
    
    // 检查红外信号，允许SHUT_DOWN按键打断（减少检查频率）
    static int stepCount = 0;
    stepCount++;
    if (stepCount % 500 == 0 && IrReceiver.decode()) {  // 每500步检查一次，减少干扰
      uint32_t command = IrReceiver.decodedIRData.command;
      uint32_t address = IrReceiver.decodedIRData.address;
      uint8_t protocol = IrReceiver.decodedIRData.protocol;
      
       // 只响应有效的SHUT_DOWN信号
       if (command == IR_KEY_SHUTDOWN && address != 0x0 && protocol != 0) {
         Serial.println("设置模式下接收到停止信号，退出设置模式");
         digitalWrite(ENABLE_PIN, HIGH);  // 禁用电机
         setMode = false;
         timingInProgress = false;
         motorRunning = false;
         stepCount = 0;
         IrReceiver.resume();
         return;
       }
      IrReceiver.resume();
    }
  }
  
  // 只在非设置模式下添加延迟，避免影响电机转动
  if (!setMode || !timingInProgress) {
    delay(50); // 短暂延迟，避免过度占用CPU
  }
  
  // 安全措施：如果不在设置模式且电机应该停止，确保电机被禁用
  if (!setMode && !motorRunning) {
    digitalWrite(ENABLE_PIN, HIGH);  // 确保电机被禁用
  }
}
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

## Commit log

2025-09-07 feature: 增加arduino工程
2025-09-08 feature: 调整选装方向和注释
2025-09-08 feature:优化转速
2025-09-08 feature: 增加方向切换
2025-09-09 feature: 重命名文件+ 增加3d模型
2025-09-09 feature: 修改注释
2025-09-10 feature: 提取config.h
2025-09-10 feature: 重命名变量
2025-09-10 feature: esp32-c3 mini修改
2025-09-10 feature: readme
    [mount.stl]
2025-09-16 feature: 修改注释，提取变量
2025-09-23 feature: 添加code文件夹，存放esp和app代码
2025-09-23 feature: app蓝牙控制
2025-09-23 feature: esp32代码修改
2025-09-23 feature: esp32代码优化
2025-09-24 feature: app ui调整
2025-09-24 feature: 添加素材文件
2025-09-24 feature: readme图片大小调整
2025-09-25 fix：设置模式下微卡
2025-09-26 feature: 压缩gif
2025-09-26 feature: 权限适配+ phy协商机制优化处理
2025-10-15 feature: esp增加开关，控制是否开启蓝牙
2025-10-15 feature: esp32 提取步进电机速度参数到config.h中
2025-10-15 feature：esp日志控制
2025-10-15 feature: 蓝牙广播优化
2026-07-02 fix:编译错误
